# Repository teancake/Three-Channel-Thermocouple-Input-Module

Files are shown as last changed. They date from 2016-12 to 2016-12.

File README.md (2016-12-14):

# Three-Channel Thermocouple Input Module (K Type) #
This repository includes the schematic and PCB design of a three-channel thermocouple input module (K-type). This module is similar to the [Adafruit thermocouple amplifier breakout board](https://www.adafruit.com/product/269), but allowing for three channels of input. This module (or breakout board) also uses MAX6675 chip and can only be connected to [K-type thermocouples](https://www.adafruit.com/products/270). MAX6675 can sense temperatures ranging from 0 to 1024 Degrees Celcius.

## Dimensions: ##
Length: 45mm/1.77in
Width: 28mm/1.1in

## Data Interface ##
The MAX6675 chip uses an SPI-compatible serial interface (only SCK and MISO). 

## Arduino Library ##
The [MAX6675 library from Adafruit](https://github.com/adafruit/MAX6675-library) can be readily used.

## The Finished Board ##
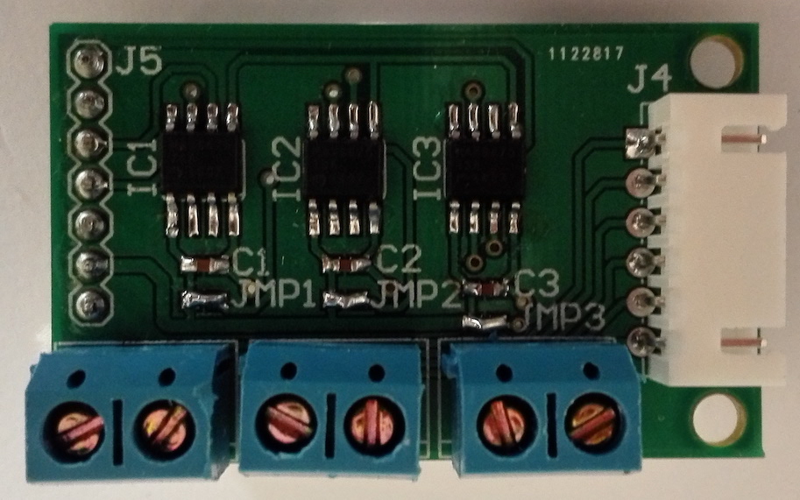
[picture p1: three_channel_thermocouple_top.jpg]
top
 
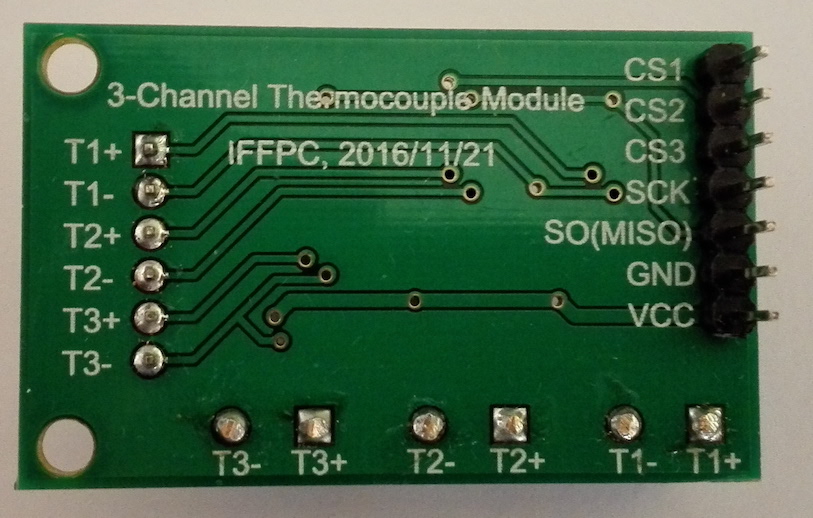
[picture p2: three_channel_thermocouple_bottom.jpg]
bottom


* Note that there are no 3.3V voltage regulators on this board. The MAX6675 chip itself accepts both 3.3V and 5V power input, but make sure the voltage level of the I/O pins are compatible with the devices connected. *

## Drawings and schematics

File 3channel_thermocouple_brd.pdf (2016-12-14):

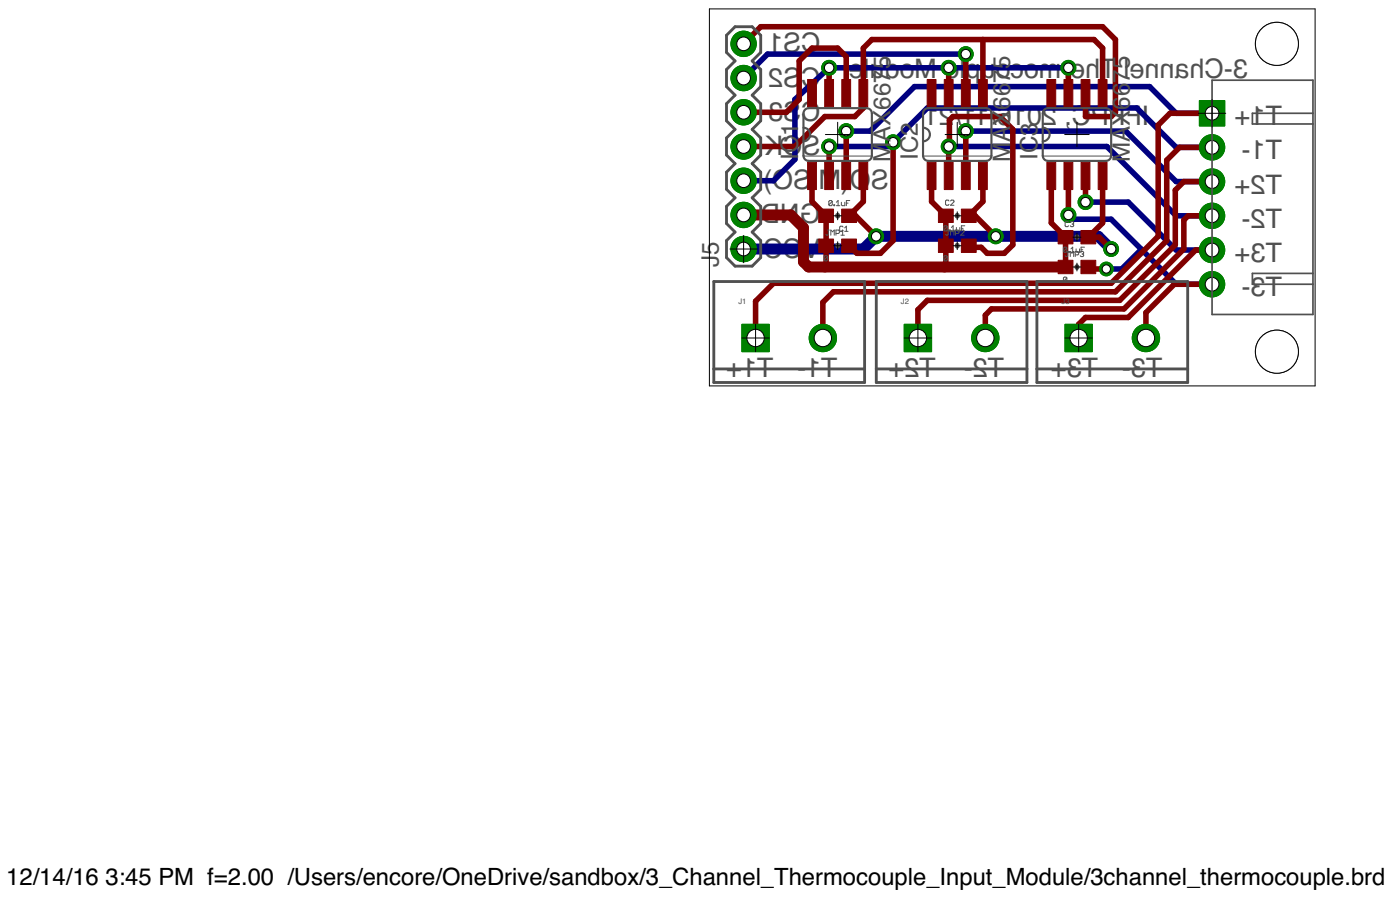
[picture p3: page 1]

12/14/16 3:45 PM f=2.00 /Users/encore/OneDrive/sandbox/3_Channel_Thermocouple_Input_Module/3channel_thermocouple.brd

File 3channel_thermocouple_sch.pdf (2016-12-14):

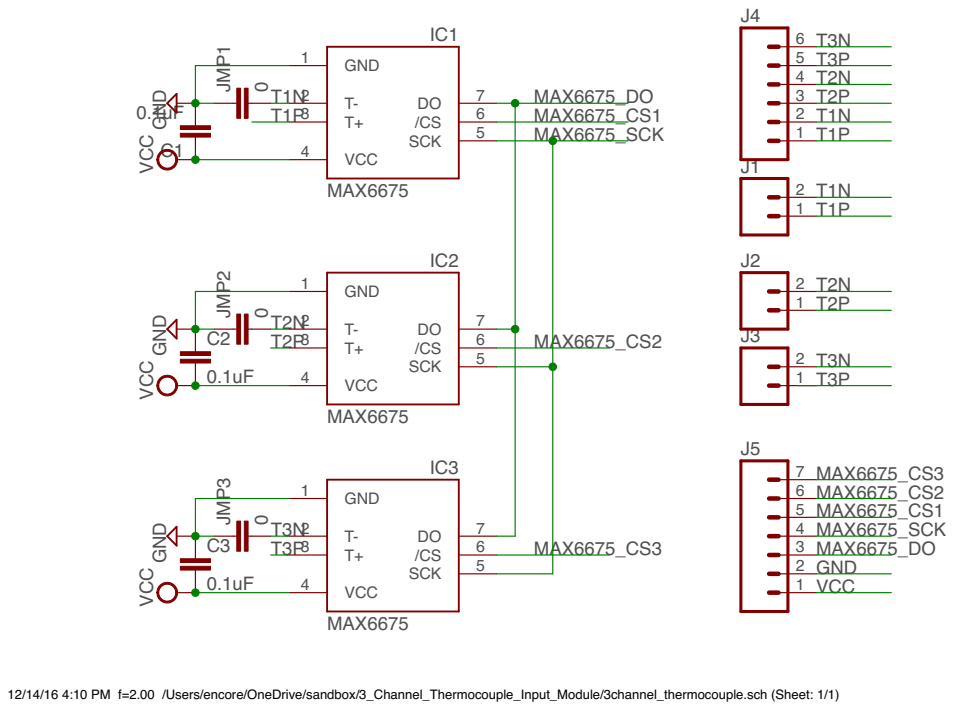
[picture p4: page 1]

12/14/16 4:10 PM f=2.00 /Users/encore/OneDrive/sandbox/3_Channel_Thermocouple_Input_Module/3channel_thermocouple.sch (Sheet: 1/1)

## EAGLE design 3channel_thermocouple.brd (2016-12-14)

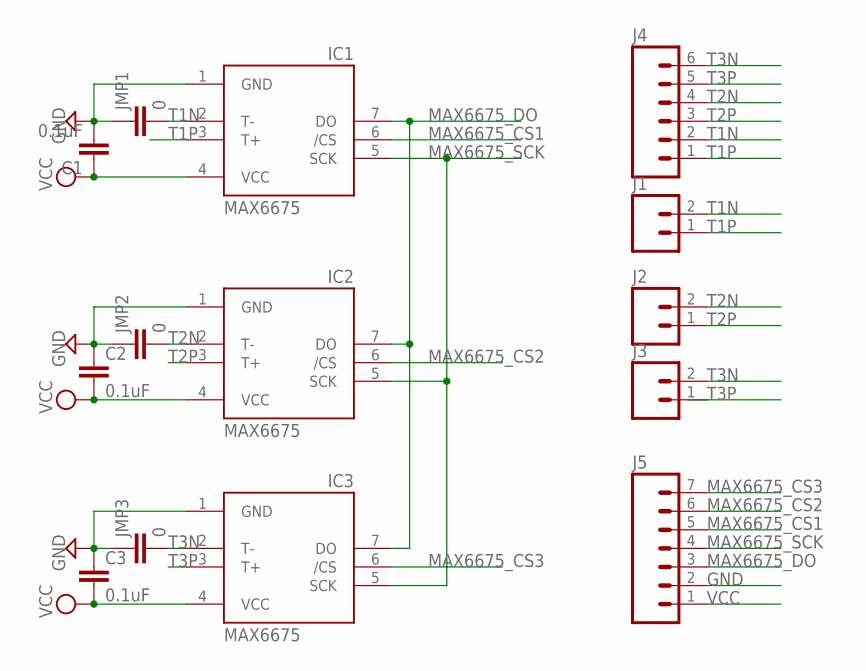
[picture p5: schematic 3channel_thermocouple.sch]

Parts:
C1, C2, C3: 0.1uF; 0603-CAP
IC1, IC2, IC3: MAX6675; SO08
J1, J2, J3: M025MM; SCREWTERMINAL-5MM-2
J4: M06; 1X6-XH-JST-S6B-RIGHTANGLE
J5: M07; 1X07
JMP1, JMP2, JMP3: 0; 0603-CAP

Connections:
GND: C1.2, C2.1, C3.1, IC1.1 (GND), IC2.1 (GND), IC3.1 (GND), J5.2, JMP1.1, JMP2.1, JMP3.1
MAX6675_CS1: IC1.6 (/CS), J5.5
MAX6675_CS2: IC2.6 (/CS), J5.6
MAX6675_CS3: IC3.6 (/CS), J5.7
MAX6675_DO: IC1.7 (DO), IC2.7 (DO), IC3.7 (DO), J5.3
MAX6675_SCK: IC1.5 (SCK), IC2.5 (SCK), IC3.5 (SCK), J5.4
T1N: IC1.2 (T-), J1.2, J4.2, JMP1.2
T1P: IC1.3 (T+), J1.1, J4.1
T2N: IC2.2 (T-), J2.2, J4.4, JMP2.2
T2P: IC2.3 (T+), J2.1, J4.3
T3N: IC3.2 (T-), J3.2, J4.6, JMP3.2
T3P: IC3.3 (T+), J3.1, J4.5
VCC: C1.1, C2.2, C3.2, IC1.4 (VCC), IC2.4 (VCC), IC3.4 (VCC), J5.1

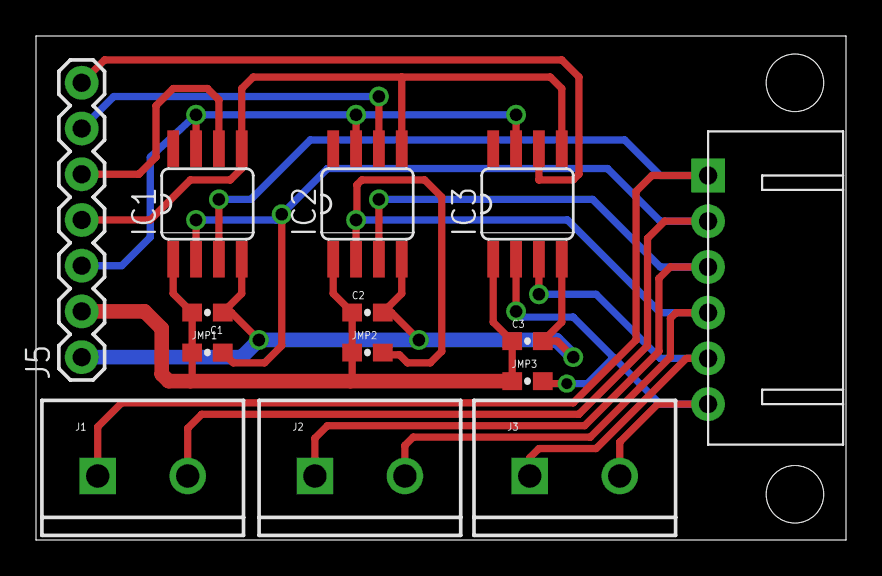
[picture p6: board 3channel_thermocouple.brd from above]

Board: 2 copper layers, 45.0 x 28.0 mm, 14 parts (0 on the bottom side), 13 nets.

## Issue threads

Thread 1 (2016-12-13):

CS1 and CS3 needs to be swapped.

teancake, 2016-12-13:
Text CS1 and CS3 on the silkscreen needs to be swapped. CS1 actually connects to the CS pin of IC3, and CS3 IC1.

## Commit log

2016-12-14 all design files.
    [3channel_thermocouple.PcbDoc, 3channel_thermocouple.brd, 3channel_thermocouple.sch]
2016-12-14 images of the finished board
